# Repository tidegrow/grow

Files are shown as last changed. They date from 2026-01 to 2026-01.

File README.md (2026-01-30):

# Tidegrow Grow

Tidegrow Grow is an experimental low-power grow light system. Boards can be chained to create custom panels.

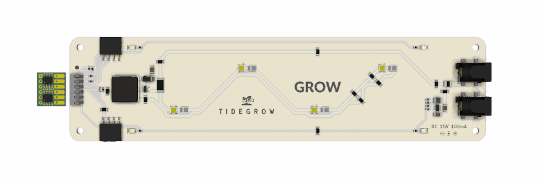
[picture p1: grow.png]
Grow


This repo contains schematics, PCB layouts, firmware and 3D-printable components.

Find more information on the [Grow product page](https://machdyne.com/product/tidegrow-grow/).

## Pinouts

### Zwölf

Grow has a [Zwölf](https://github.com/machdyne/zwolf) MCU socket that can be used to implement a timer, PWM dimming, I2C remote control, etc.

| Pin | Signal | Description |
| --- | --- | --- |
| 1 | SCL | I2C clock |
| 2 | SDA | I2C data |
| 3 | EN | Float = ON, Low = OFF |
| 4 | TEMP | Board temperature (0V - 1.1V) |
| 5 | GND | Ground |
| 6 | 3V3 | Power (3.3V) |

### I2C Headers

Grow has two I2C headers for optional remote control and I2C chaining.

```
SCL SDA GND GND
```

## Notes

These are being tested in 0.6W and 1.2W configurations. The higher power can be acheived by changing R6 from a 2ohm to 1ohm resistor.

The footprints support either four LM301B or four 2835 LEDs.

## LLM-generated code

To the extent that there is LLM-generated code in this repo, it should be space indented. Any space indented code should be carefully audited and then converted to tabs (eventually). 

## License

The contents of this repo are released under the [Lone Dynamics Open License](LICENSE.md).

Note: You can use these designs for commercial purposes but we ask that instead of producing exact clones, that you either replace our trademarks and logos with your own or add your own next to ours.

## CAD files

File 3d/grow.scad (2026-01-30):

/*
 * Tidegrow Grow
 * Copyright (c) 2025 Lone Dynamics Corporation. All rights reserved.
 *
 * required hardware:
 *  - 4 x M3 x 25mm countersunk bolts
 *  - 4 x M3 nuts
 *  - 4 x M3 countersunk magnets
 *
 */
 
$fn = 36;

tgg_pcb();
translate([0,50+2.5,0]) tgg_pcb();

//tgp_power();

translate([-100+12.5+2,0,1.6]) tgg_socket();
translate([100,0,(14/2)+1.9]) tgg_lens_left();

translate([100-(14/2)+2,0,(14/2)+1.6]) tgg_power();
translate([100,0,(14/2)+1.9]) tgg_lens_right();

//translate([100-5,-(25+1.25),-5]) tgg_coupler();
//translate([100-5,(25+1.25),-5]) tgg_coupler();

 
module tgg_pcb() {
     difference() {
        union() {
            color([0,1,0]) rcube(200,50,1.4,5);
            // zwölf
            color([0.3,0.3,0.3]) translate([-100+(7.5/2),0,1.4+3/2]) cube([7.5,16.5,3], center=true);
            // zwölf springs
            color([0.7,0.7,0.7]) translate([-100+(7.5/2),0,1.4+4]) cube([5,15,3], center=true);
            // power sockets
            color([0.2,0.2,0.2]) translate([100-(12/2),0,1.4+5.55]) cube([12,25,11.1], center=true);
        }
        translate([-100+5,25-5,-5]) cylinder(d=3, h=10);
        translate([100-5,25-5,-5]) cylinder(d=3, h=10);
        translate([-100+5,-25+5,-5]) cylinder(d=3, h=10);
        translate([100-5,-25+5,-5]) cylinder(d=3, h=10);
     }
}
 
module tgg_socket() {
  
     difference() {
        union() {
            translate([-2,0,2.5]) rcube(25,50,5,5);
            translate([-9.5,25-5,0]) cylinder(d=10, h=12.5);
            translate([-9.5,-25+5,0]) cylinder(d=10, h=12.5);
        }
        translate([-9.5,25-5,-5]) cylinder(d=3.75, h=20);
        translate([-9.5,-25+5,-5]) cylinder(d=3.75, h=20);
        translate([2,0,1.2]) rotate([0,0,0]) tgg_socket_cutout();
        
        translate([12.5,0,-5]) cylinder(d=30, h=20);
        
     }
        
}
 
module tgg_socket_cutout() {
                
    translate([-13,0,2.25]) cube([10,16.5,4.5], center=true);      
    translate([-18,0,2.25]) cube([10,16.5,20], center=true);                    
 
}
 
module tgg_power() {
    difference() {
        union() {
            translate([0,0,3.3]) rcube(10,50,4,5);
            translate([0,25-5,-7.6]) cylinder(d=10, h=12.5);
            translate([0,-25+5,-7.6]) cylinder(d=10, h=12.5);
        }
        
        translate([0,25-5,-10]) cylinder(d=3.75, h=25);
        translate([0,-25+5,-10]) cylinder(d=3.75, h=25); 
    }
}

module tgp_power() { // bloom version
    difference() {
        union() {
            translate([0,0,3.3]) rcube(10,100,4,5);
            translate([0,45,-7.6]) cylinder(d=10, h=12.5);
            translate([0,-45,-7.6]) cylinder(d=10, h=12.5);
        }
        
        translate([0,45,-10]) cylinder(d=3.75, h=25);
        translate([0,-45,-10]) cylinder(d=3.75, h=25); 
    }
}


 module tgg_coupler() {
     difference() {
        rcube(10,24.5,5,5);
        translate([0,(5+1.25),-5]) cylinder(d=3.75, h=20);
        translate([0,-(5+1.25),-5]) cylinder(d=3.75, h=20);
     }
}
 
module tgg_lens_left() {
    
    difference() {
        union() {
            color([1,0,0]) translate([-150,0,1]) rcube(100,50,6,5);
            translate([-187.5,0,0]) rcube(25,50,3.5,5);
        }
        
        translate([-100,0,-12-0.75]) rcube(176,45,20-1,5);
        
        translate([-5,25-5,-5]) cylinder(d=3.75, h=20);
        translate([-5,-25+5,-5]) cylinder(d=3.75, h=20);

        translate([-195,25-5,-10]) cylinder(d=3.75, h=25);
        translate([-195,-25+5,-10]) cylinder(d=3.75, h=25); 
        
    }
}

module tgg_lens_right() {
    
    difference() {
        union() {
            color([1,0,0]) translate([-50,0,1]) rcube(100,50,6,5);
        }
        
        translate([-10,0,-12-0.75]) rcube(176,40,20-1,5);
        
        translate([-100,0,-12-0.75]) rcube(176,45,20-1,5);
        
        translate([-5,25-5,-5]) cylinder(d=3.75, h=20);
        translate([-5,-25+5,-5]) cylinder(d=3.75, h=20);

        translate([-195,25-5,-10]) cylinder(d=3.75, h=25);
        translate([-195,-25+5,-10]) cylinder(d=3.75, h=25); 
        
    }
}


 module rcube(xx, yy, height, radius)
{
    translate([-xx/2,-yy/2,height/2])
    hull()
    {
        translate([radius,radius,0])
        cylinder(height,radius,radius,true);

        translate([xx-radius,radius,0])
        cylinder(height,radius,radius,true);

        translate([xx-radius,yy-radius,0])
        cylinder(height,radius,radius,true);

        translate([radius,yy-radius,0])
        cylinder(height,radius,radius,true);
    }
}

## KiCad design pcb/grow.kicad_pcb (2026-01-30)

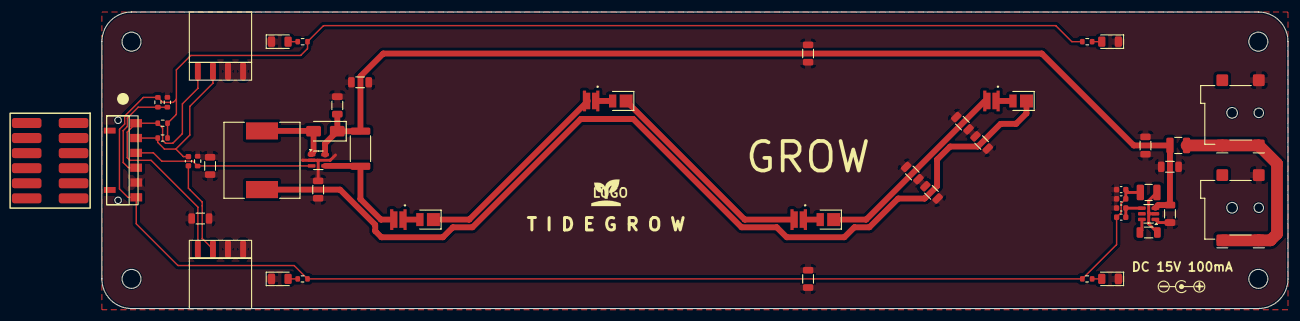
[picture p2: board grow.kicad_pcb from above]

Board: 2 copper layers, 200.0 x 50.0 mm, 58 parts (0 on the bottom side), 25 nets.

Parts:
C4, C6: 10uF30v; C_1206_3216Metric
C8: 100nF30v; C_1206_3216Metric
C9, C10: 22uF; C_0603_1608Metric
D1: SS34; D_SMA
D2, D3, D4, D5: LM301B; LED_SPMWHD32AMD5XAU0S0
D6, D7, D8, D20: LED; LED_1206_3216Metric
D9, D10, D11, D12: 660nm; LED_PLCC_2835_KBIG
F2: 1A_TRIP; Fuse_1210_3225Metric
H1, H2, H3, H4: MountingHole; MountingHole_3.2mm_M3_DIN965
J1, J5: Conn_01x04_Socket; LD-SMD-FEMALE-1x04
J2, J3: Barrel_Jack_Switch; BarrelJack_Wuerth_694108106102_2.5x5.5mm
J4: Conn_01x06; SPRING-MALE-6P-TIGHTHOLES
L1: 47uH_1.2A_CMLH1204S470MTT; L_SXN_SMDRI127
L4: 3.3uH 1.2A; L_1210_3225Metric
R1, R2, R18: 10K; R_0603_1608Metric
R3, R4, R5, R7: 1K; R_0603_1608Metric
R6: 2000mOhm; R_2512_6332Metric
R8, R11, R12, R13, R14, R15, R15#2, R17, R19, R20, R24, R25: 0R; R_1206_3216Metric
R9: 33K2; C_0603_1608Metric
R10: 10K; C_0603_1608Metric
R16: 0R; C_0603_1608Metric
R21: 20K; R_0603_1608Metric
TH1: Thermistor_NTC; R_0603_1608Metric
U2: PAM2861; SOT-23-5
U3: LD-ZWOLF
U4: AP62300TWU-7; TSOT-23-6

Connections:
/LN: D12.1_1, L1.1
/PWM_LEDW: J4.3, R18.2, U2.3 (VSET)
/PWR3V3: C9.1, C10.1, J4.6, L4.2, R1.2, R2.2, R3.2, R4.2, R5.2, R7.2, R9.2, R21.2
/PWRFUSED: C4.1, C6.1, D1.1 (K), F2.2, R6.1, U2.5 (VIN), U4.3 (VIN)
/PWRIN: F2.1, J2.1, J3.1
/SCL: J1.4, J4.1, J5.1, R2.1
/SDA: J1.3, J4.2, J5.2, R1.1, R16.1, R16.2
/SW: C8.2, L4.1, U4.2 (SW)
/TEMP: J4.4, R21.1, TH1.1
GND: C4.2, C6.2, C9.2, C10.2, D6.1 (K), D7.1 (K), D8.1 (K), D20.1 (K), J1.1, J1.2, J2.2, J3.2, J4.5, J5.3, J5.4, R8.1, R8.2, R10.1, R11.1, R11.2, R12.1, R12.2, R13.1, R13.2, R14.1, R14.2, R15.1, R15.2, R15#2.1, R15#2.2, R17.1, R17.2, R18.1, R19.1, R19.2, R20.1, R20.2, R24.1, R24.2, R25.1, R25.2, TH1.2, U2.2 (GND), U4.1 (GND)
unnamed: D1.2 (A), L1.2, U2.1 (LX)
unnamed: D2.1_1, D2.1_2, D9.2_2
unnamed: D3.2_1, D3.2_2, D9.1_1
unnamed: D6.2 (A), R4.1
unnamed: D7.2 (A), R5.1
unnamed: D8.2 (A), R7.1
unnamed: D4.2_1, D4.2_2, D10.1_1
unnamed: D3.1_1, D3.1_2, D10.2_2
unnamed: D5.2_1, D5.2_2, D11.1_1
unnamed: D4.1_1, D4.1_2, D11.2_2
unnamed: D5.1_1, D5.1_2, D12.2_2
unnamed: D20.2 (A), R3.1
unnamed: D2.2_1, D2.2_2, R6.2, U2.4 (ISENSE)
unnamed: C8.1, U4.6 (BST)
unnamed: R9.1, R10.2, U4.4 (FB)

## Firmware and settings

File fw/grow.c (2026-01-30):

/*
 * Tidegrow Grow Firmware for Zwölf LS10 module
 * Copyright (c) 2025 Lone Dynamics Corporation. All rights reserved.
 *
 */

#include "ch32v003fun.h"
#include "i2c_slave.h"
#include <stdio.h>

#define GROW_POWER	100	// pwm duty cycle (percentage)
#define GROW_MINS	(14*60)	// minutes on per 24-hour cycle (14 hours = 840 mins)

// --

#define GROW_I2C_ADDR	0x99

#define GROW_I2C_SCL_PORT GPIOC	// ZA
#define GROW_I2C_SCL_PIN 2

#define GROW_I2C_SDA_PORT GPIOC	// ZB
#define GROW_I2C_SDA_PIN 1

#define GROW_PWM_PORT GPIOD		// ZC (low = off, float = on full)
#define GROW_PWM_PIN 6

#define GROW_TEMP_PORT GPIOD		// ZD (temperature, 0V - 1.1V)
#define GROW_TEMP_PIN 5

volatile uint8_t i2c_regs[32] = {0x00};

// Time tracking for GROW_MINS functionality
// Counts minutes from power-on (0-1439), then wraps back to 0 for 24-hour cycle
// Light turns ON at power-on (minute 0), stays on for GROW_MINS,
// then turns OFF for (1440-GROW_MINS), creating a repeating 24-hour cycle
volatile uint32_t seconds_counter = 0;
volatile uint16_t current_minute = 0;
volatile uint8_t light_on = 0;

void i2c_onWrite(uint8_t reg, uint8_t length);
void i2c_onRead(uint8_t reg);
void update_light_state(void);
void configure_pwm_power(void);

void adc_init(void)
{
	// ADCCLK = 24 MHz => RCC_ADCPRE = 0: divide by 2
	RCC->CFGR0 &= ~(0x1F<<11);

	// Enable ADC
	RCC->APB2PCENR |= RCC_APB2Periph_ADC1;
	
	// PD5 is analog input chl 5
	GPIOD->CFGLR &= ~(0xf<<(4*5));	// CNF = 00: Analog, MODE = 00: Input
	
	// Reset the ADC to init all regs
	RCC->APB2PRSTR |= RCC_APB2Periph_ADC1;
	RCC->APB2PRSTR &= ~RCC_APB2Periph_ADC1;
	
	// Set up single conversion for ch 5
	ADC1->RSQR1 = 0;
	ADC1->RSQR2 = 0;
	ADC1->RSQR3 = 5;	// 0-9 for 8 ext inputs and two internals
	
	// set sampling time for chl 5
	ADC1->SAMPTR2 &= ~(ADC_SMP0<<(3*5));
   // Possible times: 0->3,1->9,2->15,3->30,4->43,5->57,6->73,7->241 cycles
   ADC1->SAMPTR2 = 1/*9 cycles*/ << (3/*offset per channel*/ * 7/*channel*/);

	// turn on ADC and set rule group to sw trig
	ADC1->CTLR2 |= ADC_ADON | ADC_EXTSEL;

	// Reset calibration
	ADC1->CTLR2 |= ADC_RSTCAL;
	while(ADC1->CTLR2 & ADC_RSTCAL);
	
	// Calibrate
	ADC1->CTLR2 |= ADC_CAL;
	while(ADC1->CTLR2 & ADC_CAL);
	
	// should be ready for SW conversion now
}

uint16_t adc_get(void)
{
	// start sw conversion (auto clears)
	ADC1->CTLR2 |= ADC_SWSTART;
	
	// wait for conversion complete
	while(!(ADC1->STATR & ADC_EOC));
	
	// get result
	return ADC1->RDATAR;
}

// mask for the CCxP bits
// We use positive polarity (0x00) because we invert in software for open-drain PWM
#define TIM2_DEFAULT 0x00

void pwm_init(void) {

	// Enable GPIOD and TIM2
	RCC->APB2PCENR |= RCC_APB2Periph_GPIOD;
	RCC->APB1PCENR |= RCC_APB1Periph_TIM2;

	// Reset TIM2 to init all regs
	RCC->APB1PRSTR |= RCC_APB1Periph_TIM2;
	RCC->APB1PRSTR &= ~RCC_APB1Periph_TIM2;
	
	// SMCFGR: default clk input is CK_INT
	// set TIM2 clock prescaler divider 
	// For 48MHz clock: 48MHz / (PSC+1) / (ATRLR+1) = PWM frequency
	// Target: ~390 Hz = 48MHz / 480 / 256
	TIM2->PSC = 479;  // 48MHz / 480 = 100kHz timer clock
	// set PWM total cycle width
	TIM2->ATRLR = 255;  // 100kHz / 256 = ~390 Hz PWM frequency
	
	// for channel 3, let CCxS stay 00 (output), set OCxM to 110 (PWM I)
	// enabling preload causes the new pulse width in compare capture register only to come into effect when UG bit in SWEVGR is set (= initiate update) (auto-clears)
	TIM2->CHCTLR2 |= TIM_OC3M_2 | TIM_OC3M_1 | TIM_OC3PE;

	// Set initial PWM value to 0 (off)
	TIM2->CH3CVR = 0;

	// CTLR1: default is up, events generated, edge align
	// enable auto-reload of preload
	TIM2->CTLR1 |= TIM_ARPE;

	// DON'T enable Channel 3 output yet - let configure_pwm_power do it
	// Just ensure polarity bit is cleared
	TIM2->CCER &= ~TIM_CC3P;

	// initialize counter
	TIM2->SWEVGR |= TIM_UG;

	// Enable TIM2
	TIM2->CTLR1 |= TIM_CEN;
}

void pwm_setpw(uint16_t width) {
	TIM2->CH3CVR = width;  // PD6 is TIM2_CH3 with full remap
	TIM2->SWEVGR |= TIM_UG; // load new value in compare capture register
}

// Configure PWM based on GROW_POWER setting
void configure_pwm_power(void) {
	if (GROW_POWER >= 100) {
		// 100% power - float the pin (high-Z state) per PAM2861 datasheet
		TIM2->CCER &= ~TIM_CC3E;  // Disable PWM output on CH3
		(GROW_PWM_PORT)->CFGLR &= ~(0xf<<(4*GROW_PWM_PIN));
		(GROW_PWM_PORT)->CFGLR |= (GPIO_CNF_IN_FLOATING)<<(4*GROW_PWM_PIN);
	} else if (GROW_POWER == 0) {
		// 0% power - drive LOW to turn off per PAM2861 datasheet
		TIM2->CCER &= ~TIM_CC3E;  // Disable PWM on CH3
		(GROW_PWM_PORT)->CFGLR &= ~(0xf<<(4*GROW_PWM_PIN));
		(GROW_PWM_PORT)->CFGLR |= (GPIO_Speed_10MHz | GPIO_CNF_OUT_PP)<<(4*GROW_PWM_PIN);
		(GROW_PWM_PORT)->BCR = (1 << GROW_PWM_PIN);  // Set LOW
	} else {
		// 1-99% power - use open-drain PWM without inversion
		// Configure pin as PWM output, OPEN-DRAIN
		(GROW_PWM_PORT)->CFGLR &= ~(0xf<<(4*GROW_PWM_PIN));
		(GROW_PWM_PORT)->CFGLR |= (GPIO_Speed_10MHz | GPIO_CNF_OUT_OD_AF)<<(4*GROW_PWM_PIN);
		
		// Enable PWM output on CH3 without polarity inversion
		TIM2->CCER &= ~TIM_CC3P;  // Clear polarity bit (non-inverted)
		TIM2->CCER |= TIM_CC3E;
		
		// Non-inverted: higher PWM value = more time "high" (floating) = brighter
		uint16_t pwm_value = (uint32_t)(GROW_POWER * 255) / 100;
		pwm_setpw(pwm_value);
	}
}

// Update light on/off state based on GROW_MINS
// Runs on GROW_MINS, then off for (1440-GROW_MINS), repeating every 24 hours (1440 mins)
void update_light_state(void) {
	if (GROW_MINS >= 1440) {
		// Always on (24 hours or more)
		light_on = 1;
	} else if (GROW_MINS == 0) {
		// Always off
		light_on = 0;
	} else {
		// On for GROW_MINS minutes, then off for (1440-GROW_MINS) minutes
		// Example: GROW_MINS=840 (14 hrs) means on for mins 0-839, off for mins 840-1439
		light_on = (current_minute < GROW_MINS) ? 1 : 0;
	}
	
	// Apply the state
	if (light_on) {
		configure_pwm_power();
	} else {
		// Turn off - set pin low
		TIM2->CCER &= ~TIM_CC3E;  // Disable PWM on CH3
		(GROW_PWM_PORT)->CFGLR &= ~(0xf<<(4*GROW_PWM_PIN));
		(GROW_PWM_PORT)->CFGLR |= (GPIO_Speed_10MHz | GPIO_CNF_OUT_PP)<<(4*GROW_PWM_PIN);
		(GROW_PWM_PORT)->BCR = (1 << GROW_PWM_PIN);  // Set low
	}
}

// SysTick interrupt handler for time tracking
void SysTick_Handler(void) __attribute__((interrupt));
void SysTick_Handler(void) {
	seconds_counter++;
	
	// Update minute counter every 60 seconds
	if (seconds_counter >= 60) {
		seconds_counter = 0;
		current_minute++;
		if (current_minute >= 1440) {  // 24 hours = 1440 minutes
			current_minute = 0;
		}
		// Update light state when minute changes
		update_light_state();
	}
	
	SysTick->SR = 0;  // Clear interrupt flag
}

int main()
{

	SystemInit();
	Delay_Ms( 100 );
	funGpioInitAll();

	// TEMP
	(GROW_TEMP_PORT)->CFGLR &= ~(0xf<<(4*GROW_TEMP_PIN));
	(GROW_TEMP_PORT)->CFGLR |= (GPIO_CNF_IN_FLOATING)<<(4*GROW_TEMP_PIN);

	// configure I2C slave
   funPinMode(PC1, GPIO_CFGLR_OUT_10Mhz_AF_OD); // SDA
   funPinMode(PC2, GPIO_CFGLR_OUT_10Mhz_AF_OD); // SCL

//	SetupI2CSlave(GROW_I2C_ADDR, i2c_regs, sizeof(i2c_regs),
//		i2c_onWrite, i2c_onRead, false);

	// init adc
	adc_init();

	// Configure AFIO for TIM2 remap (PD6 = TIM2_CH1)
	RCC->APB2PCENR |= RCC_APB2Periph_AFIO;
	AFIO->PCFR1 |= AFIO_PCFR1_TIM2_REMAP;

	// pwm init
	pwm_init();

	// Setup SysTick for 1 second interrupts (48MHz / 48000000 = 1Hz)
	SysTick->CTLR = 0;  // Disable during setup
	SysTick->CMP = 48000000 - 1;  // Compare value for 1 second
	SysTick->CNT = 0;  // Clear counter
	SysTick->CTLR = 0x0F;  // Enable SysTick with interrupt, HCLK source
	
	NVIC_EnableIRQ(SysTicK_IRQn);

	// Initialize light state IMMEDIATELY before any printf delays
	update_light_state();

	// Now print banner and info
	printf("\r\n\r\n");
	printf("=== === ==  ===  == === === = = \r\n");
	printf(" =   =  = = ==  = = ==  = = === \r\n");
	printf(" =  === ==  === === = = === === \r\n");
	printf("\r\n\r\ngrow console\r\n\r\n");
	printf("GROW_POWER: %d%%\r\n", GROW_POWER);
	printf("GROW_MINS: %d minutes (%d hrs %d mins)\r\n", 
		GROW_MINS, GROW_MINS/60, GROW_MINS%60);
	
	printf("\r\nLight initialized: %s\r\n", light_on ? "ON" : "OFF");

	printf("\r\n24-hour cycle started at power-on\r\n");
	printf("Lights ON for %d mins, OFF for %d mins\r\n\r\n", 
		GROW_MINS, 1440-GROW_MINS);

	while(1)
	{
		printf("Cycle minute: %d/1440 (%02d:%02d), Light: %s", 
			current_minute, current_minute/60, current_minute%60, 
			light_on ? "ON " : "OFF");
		if (light_on && current_minute < GROW_MINS) {
			printf(" (%d mins remaining)", GROW_MINS - current_minute);
		} else if (!light_on && current_minute >= GROW_MINS) {
			printf(" (%d mins until next cycle)", 1440 - current_minute);
		}
		printf("\r\n");
		
		Delay_Ms( 5000 );

		uint16_t adcval = adc_get();
		printf("Temperature ADC: %d\r\n", adcval);
	}

}

void i2c_onWrite(uint8_t reg, uint8_t length) {
	printf("i2c_onWrite reg: %x len: %x val: %x\r\n", reg, length,
		i2c_regs[reg]);
	if (reg == 0x10) {
	}
}

void i2c_onRead(uint8_t reg) {
	printf("i2c_onRead reg: %x val: %x\r\n", reg, i2c_regs[reg]);
}

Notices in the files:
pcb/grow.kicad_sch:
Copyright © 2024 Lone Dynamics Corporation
